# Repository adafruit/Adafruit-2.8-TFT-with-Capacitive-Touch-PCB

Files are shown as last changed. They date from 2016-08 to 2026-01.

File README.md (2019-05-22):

## Adafruit 2.8 TFT with Capacitive Touch PCB
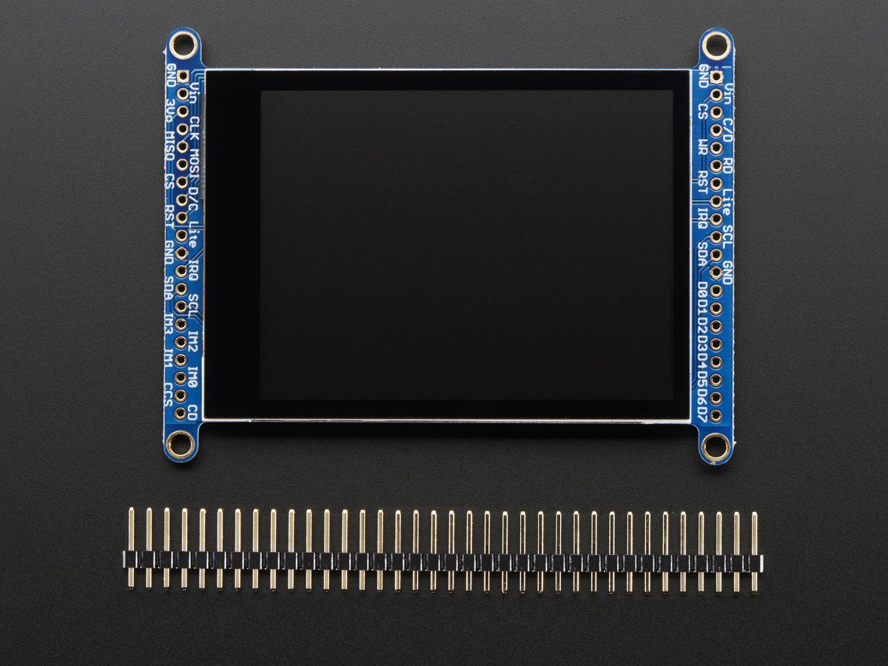
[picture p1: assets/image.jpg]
<a href="http://www.adafruit.com/products/2090"><br/>
Click here to purchase one from the Adafruit shop</a>

Add some jazz & pizazz to your project with a color capactive touchscreen LCD. This TFT display is big (2.8" diagonal) bright (4 white-LED backlight) and colorful! 240x320 pixels with individual RGB pixel control, this has way more resolution than a black and white 128x64 display. As a bonus, this display has a capacitive single-touch touchscreen attached to it already, so you can detect finger presses anywhere on the screen. (We also have a resistive touchscreen version of this display breakout)

This display has a controller built into it with RAM buffering, so that almost no work is done by the microcontroller. The display can be used in two modes: 8-bit and SPI. For 8-bit mode, you'll need 8 digital data lines and 4 or 5 digital control lines to read and write to the display (12 lines total). SPI mode requires only 5 pins total (SPI data in, data out, clock, select, and d/c) but is slower than 8-bit mode. In addition, 2 I2C pins are required for the touch screen controller.

We wrapped up this display into an easy-to-use breakout board, with SPI connections on one end and 8-bit on the other. Both are 3-5V compliant with high-speed level shifters so you can use with any microcontroller. If you're going with SPI mode, you can also take advantage of the onboard MicroSD card socket to display images. (The microSD card not included, but any will work).

PCB files for the Adafruit 2.8" TFT with Capacitive Touch PCB. The format is EagleCAD schematic and board layout
- https://www.adafruit.com/products/2090

### License

Adafruit invests time and resources providing this open source design, please support Adafruit and open-source hardware by purchasing products from [Adafruit](https://www.adafruit.com)!

All text above must be included in any redistribution

Designed by Limor Fried/Ladyada for Adafruit Industries.
Creative Commons Attribution/Share-Alike, all text above must be included in any redistribution. 
See license.txt for additional information.

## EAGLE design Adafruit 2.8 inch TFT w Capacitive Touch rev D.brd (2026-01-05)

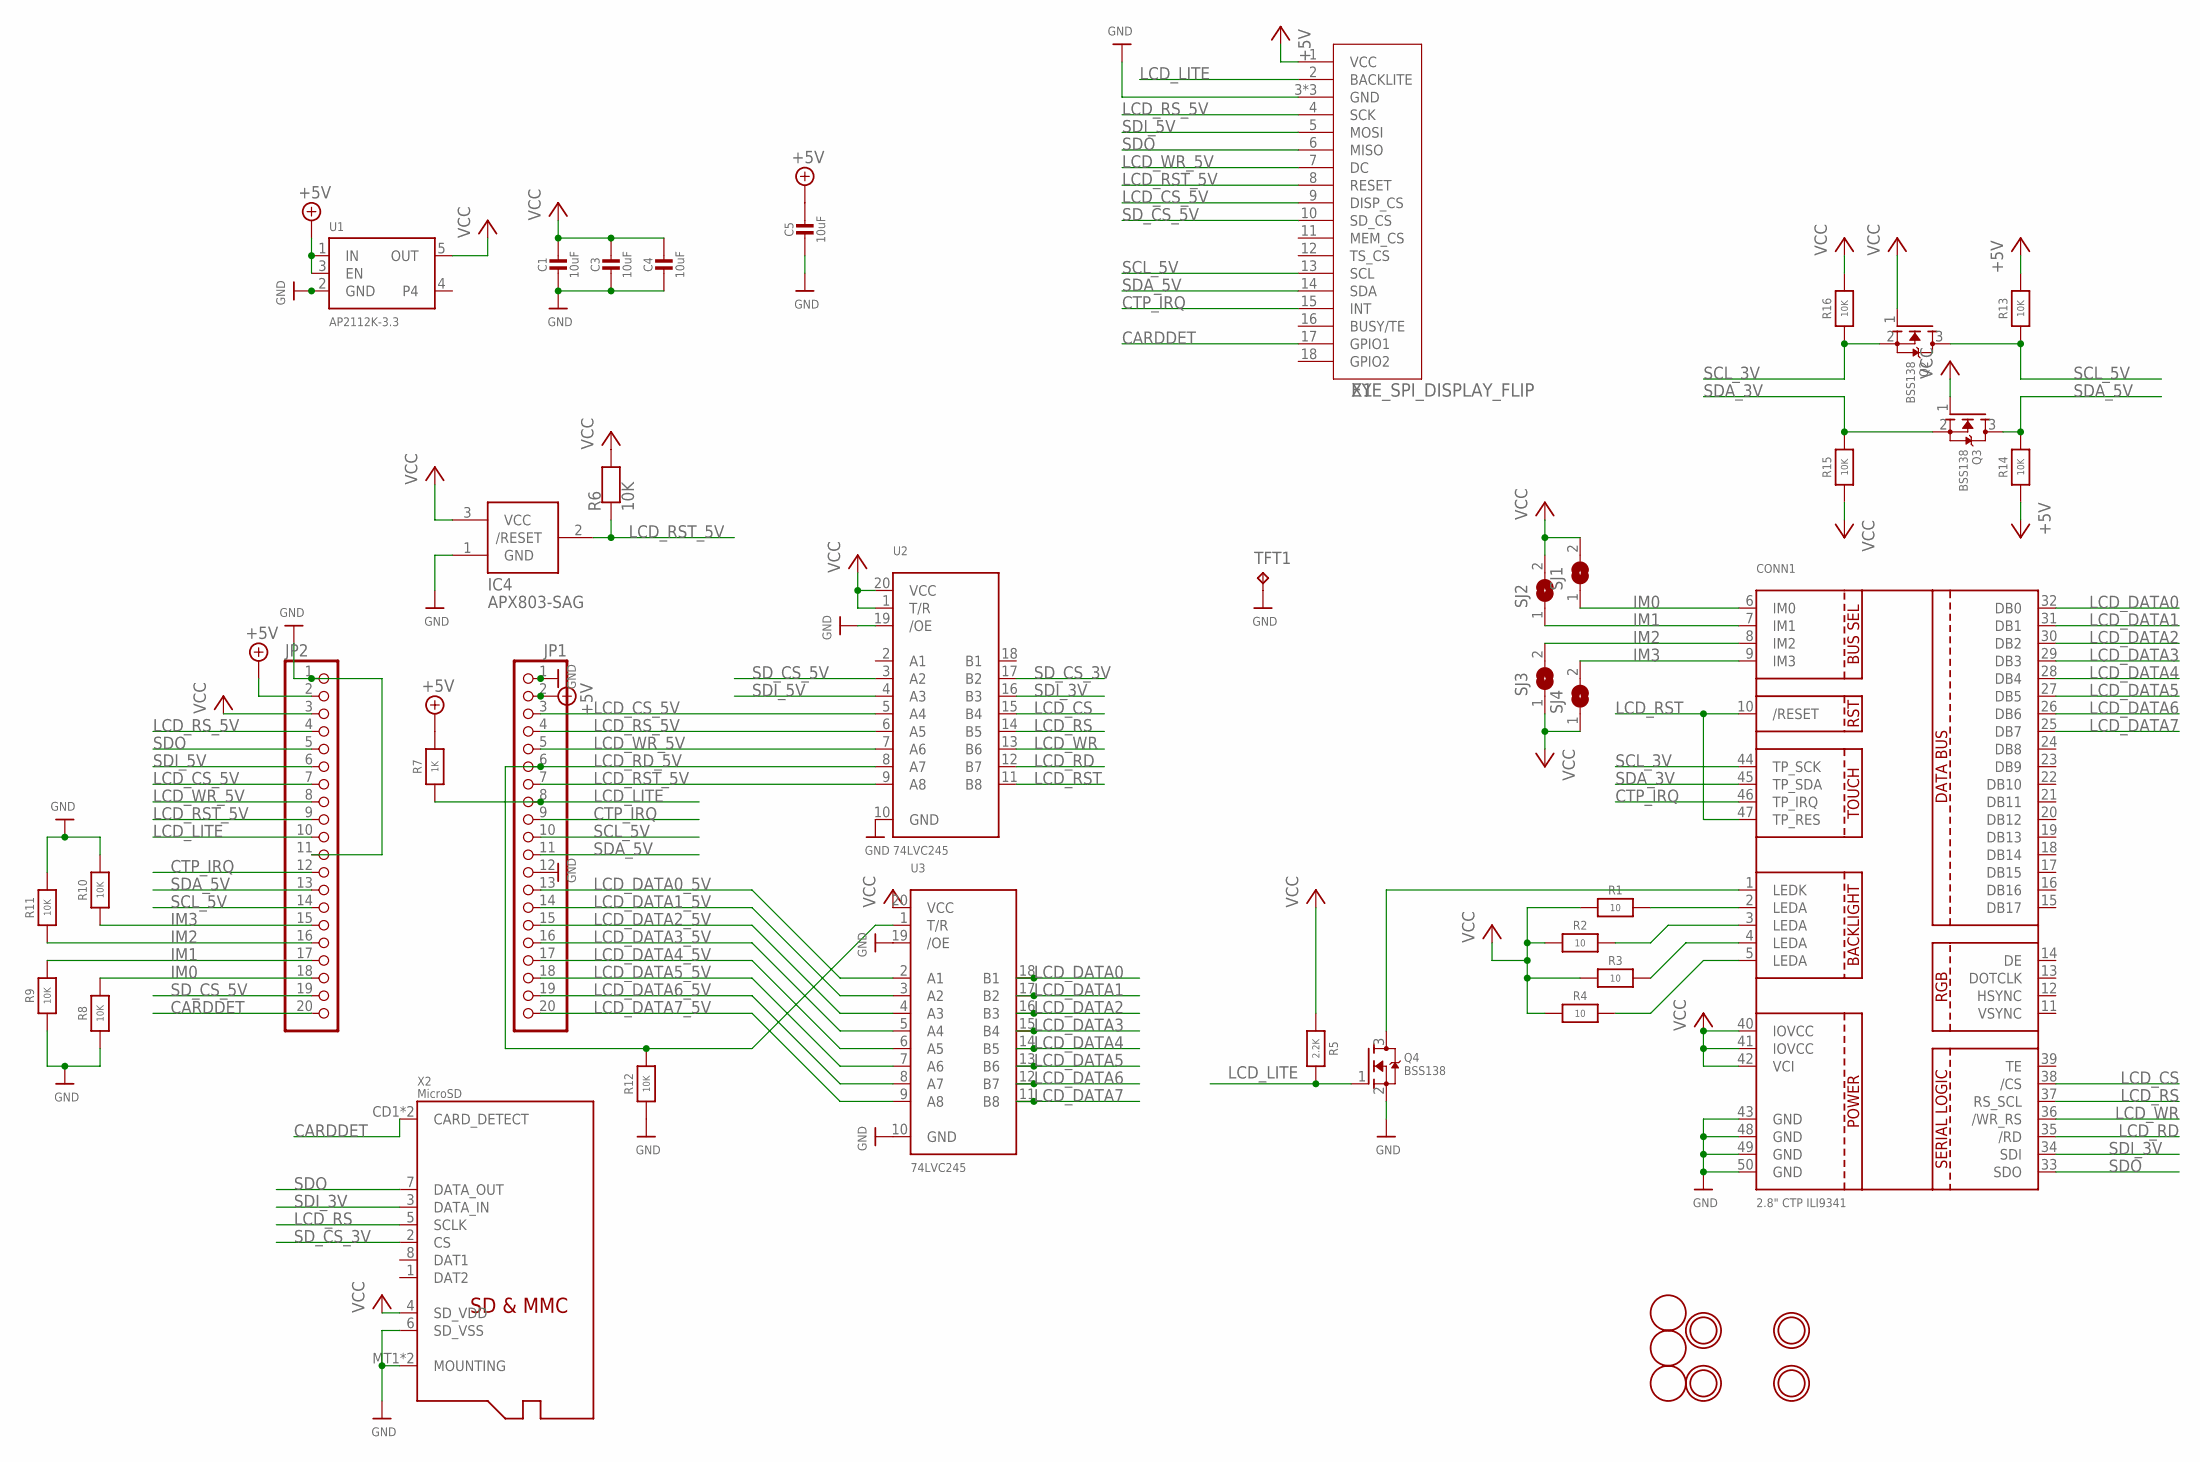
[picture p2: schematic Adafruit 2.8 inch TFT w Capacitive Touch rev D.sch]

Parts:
C1, C3, C4, C5: 10uF; 0805-NO
CONN1: 2.8" CTP ILI9341; TFT_2.83IN_240X320_50PIN
IC4: APX803-SAG; SOT23-WIDE
JP1, JP2: HEADER-1X20ROUND; 1X20_ROUND
Q2, Q3, Q4: BSS138; SOT23-WIDE
R1, R2, R3, R4: 10; 0603-NO
R5: 2.2K; 0603-NO
R6, R8, R9, R10, R11, R12, R13, R14, R15, R16: 10K; 0603-NO
R7: 1K; 0603-NO
SJ1, SJ2, SJ3, SJ4: SOLDERJUMPER; SOLDERJUMPER_ARROW_NOPASTE
TFT1: 2.8in CTP TFT; TP06R
U1: AP2112K-3.3; SOT23-5; JLC_ROTATION 0
U2, U3: 74LVC245; TSSOP20
U$7, U$15, U$16, U$17: MOUNTINGHOLE3.0THIN; MOUNTINGHOLE_3.0_PLATEDTHIN
U$9, U$11, U$23: FIDUCIAL; FIDUCIAL_1MM
X1: EYE_SPI_DISPLAY_FLIP; EYE_SPI_DISPLAY_BOTCONTACT
X2: MicroSD; MICROSD

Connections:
+5V: C5.1, JP1.2, JP2.2, R7.2, R13.2, R14.1, U1.1 (IN), U1.3 (EN), X1.1 (VCC)
CARDDET: JP2.20, X1.17 (GPIO1), X2.CD1 (CARD_DETECT), X2.CD2 (CARD_DETECT)
CTP_IRQ: CONN1.46 (TP_IRQ), JP1.9, JP2.12, X1.15 (INT)
GND: C1.2, C3.2, C4.2, C5.2, CONN1.43 (GND), CONN1.48 (GND), CONN1.49 (GND), CONN1.50 (GND), IC4.1 (GND), JP1.1, JP1.12, JP2.1, JP2.11, Q4.2 (S), R8.1, R9.1, R10.2, R11.2, R12.1, TFT1.TP, U1.2 (GND), U2.10 (GND), U2.19 (/OE), U3.10 (GND), U3.19 (/OE), X1.3 (GND), X1.SUPPORT1 (GND), X1.SUPPORT2 (GND), X2.6 (SD_VSS), X2.MT1 (MOUNTING), X2.MT2 (MOUNTING)
IM0: CONN1.6 (IM0), JP2.18, R8.2, SJ1.1
IM1: CONN1.7 (IM1), JP2.17, R9.2, SJ2.1
IM2: CONN1.8 (IM2), JP2.16, R11.1, SJ3.2
IM3: CONN1.9 (IM3), JP2.15, R10.1, SJ4.2
LCD_CS: CONN1.38 (/CS), U2.15 (B4)
LCD_CS_5V: JP1.3, JP2.7, U2.5 (A4), X1.9 (DISP_CS)
LCD_DATA0: CONN1.32 (DB0), U3.18 (B1)
LCD_DATA0_5V: JP1.13, U3.2 (A1)
LCD_DATA1: CONN1.31 (DB1), U3.17 (B2)
LCD_DATA1_5V: JP1.14, U3.3 (A2)
LCD_DATA2: CONN1.30 (DB2), U3.16 (B3)
LCD_DATA2_5V: JP1.15, U3.4 (A3)
LCD_DATA3: CONN1.29 (DB3), U3.15 (B4)
LCD_DATA3_5V: JP1.16, U3.5 (A4)
LCD_DATA4: CONN1.28 (DB4), U3.14 (B5)
LCD_DATA4_5V: JP1.17, U3.6 (A5)
LCD_DATA5: CONN1.27 (DB5), U3.13 (B6)
LCD_DATA5_5V: JP1.18, U3.7 (A6)
LCD_DATA6: CONN1.26 (DB6), U3.12 (B7)
LCD_DATA6_5V: JP1.19, U3.8 (A7)
LCD_DATA7: CONN1.25 (DB7), U3.11 (B8)
LCD_DATA7_5V: JP1.20, U3.9 (A8)
LCD_LITE: JP1.8, JP2.10, Q4.1 (G), R5.2, R7.1, X1.2 (BACKLITE)
LCD_RD: CONN1.35 (/RD), U2.12 (B7)
LCD_RD_5V: JP1.6, R12.2, U2.8 (A7), U3.1 (T/R)
LCD_RS: CONN1.37 (RS_SCL), U2.14 (B5), X2.5 (SCLK)
LCD_RST: CONN1.10 (/RESET), CONN1.47 (TP_RES), U2.11 (B8)
LCD_RST_5V: IC4.2 (/RESET), JP1.7, JP2.9, R6.1, U2.9 (A8), X1.8 (RESET)
LCD_RS_5V: JP1.4, JP2.4, U2.6 (A5), X1.4 (SCK)
LCD_WR: CONN1.36 (/WR_RS), U2.13 (B6)
LCD_WR_5V: JP1.5, JP2.8, U2.7 (A6), X1.7 (DC)
unnamed: CONN1.5 (LEDA), R4.2
unnamed: CONN1.2 (LEDA), R1.2
unnamed: CONN1.3 (LEDA), R2.2
unnamed: CONN1.4 (LEDA), R3.2
unnamed: CONN1.1 (LEDK), Q4.3 (D)
SCL_3V: CONN1.44 (TP_SCK), Q2.2 (S), R16.1
SCL_5V: JP1.10, JP2.14, Q2.3 (D), R13.1, X1.13 (SCL)
SDA_3V: CONN1.45 (TP_SDA), Q3.2 (S), R15.2
SDA_5V: JP1.11, JP2.13, Q3.3 (D), R14.2, X1.14 (SDA)
SDI_3V: CONN1.34 (SDI), U2.16 (B3), X2.3 (DATA_IN)
SDI_5V: JP2.6, U2.4 (A3), X1.5 (MOSI)
SDO: CONN1.33 (SDO), JP2.5, X1.6 (MISO), X2.7 (DATA_OUT)
SD_CS_3V: U2.17 (B2), X2.2 (CS)
SD_CS_5V: JP2.19, U2.3 (A2), X1.10 (SD_CS)
VCC: C1.1, C3.1, C4.1, CONN1.40 (IOVCC), CONN1.41 (IOVCC), CONN1.42 (VCI), IC4.3 (VCC), JP2.3, Q2.1 (G), Q3.1 (G), R1.1, R2.1, R3.1, R4.1, R5.1, R6.2, R15.1, R16.2, SJ1.2, SJ2.2, SJ3.1, SJ4.1, U1.5 (OUT), U2.1 (T/R), U2.20 (VCC), U3.20 (VCC), X2.4 (SD_VDD)

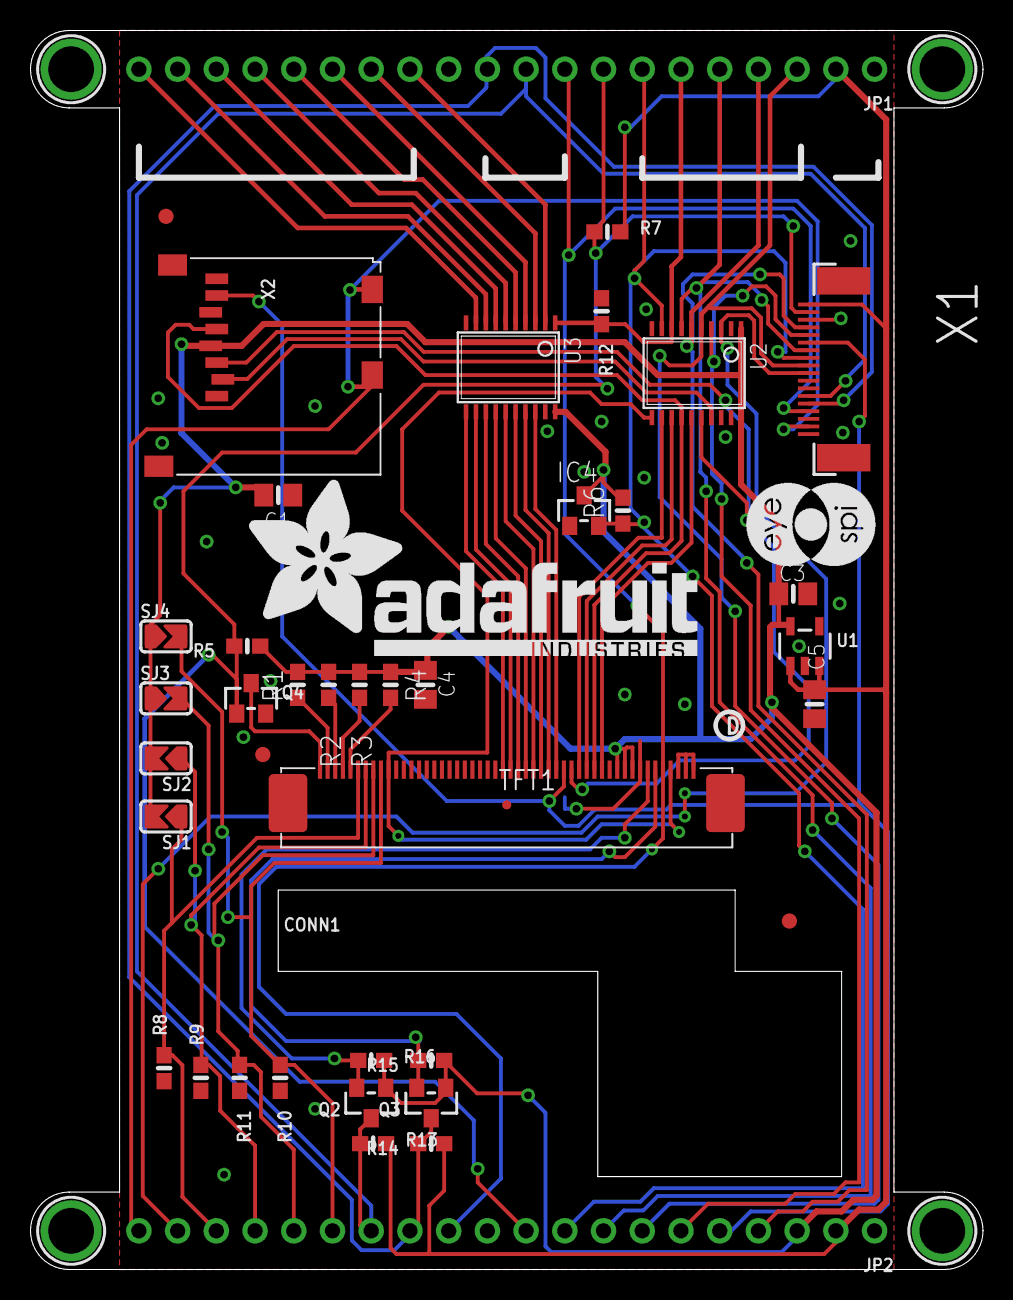
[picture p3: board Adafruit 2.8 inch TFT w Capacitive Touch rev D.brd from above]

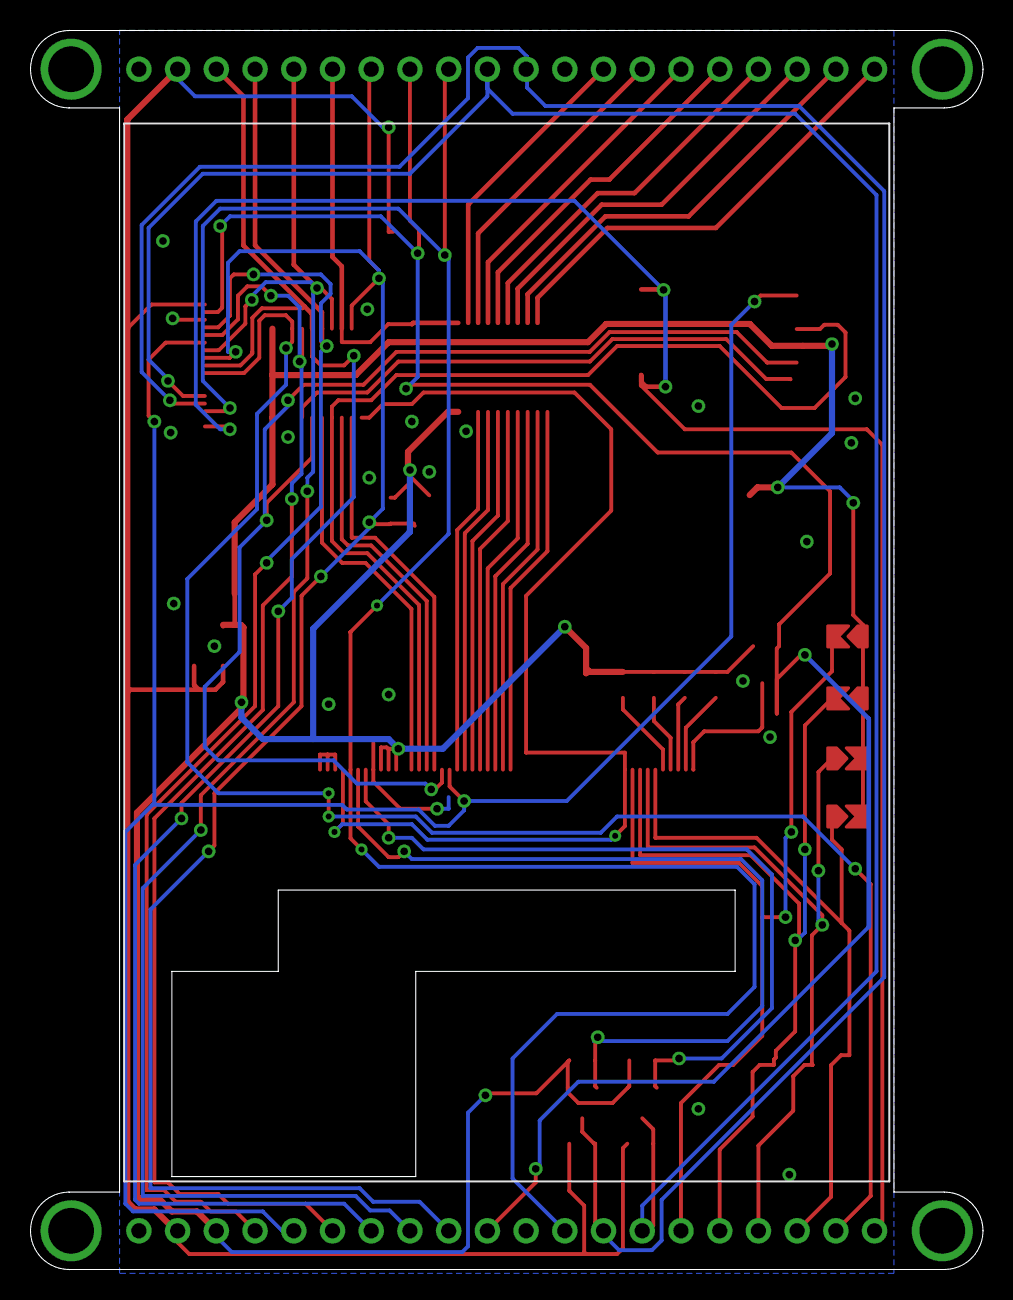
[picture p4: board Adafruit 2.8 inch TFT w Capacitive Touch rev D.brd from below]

Board: 2 copper layers, 62.5 x 81.3 mm, 144 parts (41 on the bottom side), 50 nets.

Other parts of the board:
PLABEL0: PLABEL0
PLABEL1: PLABEL1
PLABEL2: PLABEL2
PLABEL3: PLABEL3
PLABEL4: PLABEL4
PLABEL5: PLABEL5
PLABEL6: PLABEL6
PLABEL7: PLABEL7
PLABEL8: PLABEL8
PLABEL9: PLABEL9
PLABEL10: PLABEL10
PLABEL11: PLABEL11
PLABEL12: PLABEL12
PLABEL13: PLABEL13
PLABEL14: PLABEL14
PLABEL15: PLABEL15
PLABEL16: PLABEL16
PLABEL17: PLABEL17
PLABEL18: PLABEL18
PLABEL19: PLABEL19
PLABEL20: PLABEL20
PLABEL21: PLABEL21
PLABEL22: PLABEL22
PLABEL23: PLABEL23
PLABEL24: PLABEL24
PLABEL25: PLABEL25
PLABEL26: PLABEL26
PLABEL27: PLABEL27
PLABEL28: PLABEL28
PLABEL29: PLABEL29
PLABEL30: PLABEL30
PLABEL31: PLABEL31
PLABEL32: PLABEL32
PLABEL33: PLABEL33
PLABEL34: PLABEL34
PLABEL35: PLABEL35
PLABEL36: PLABEL36
PLABEL37: PLABEL37
PLABEL38: PLABEL38
PLABEL39: PLABEL39
PLABEL40: PLABEL40
PLABEL41: PLABEL41
PLABEL42: PLABEL42
PLABEL43: PLABEL43
PLABEL44: PLABEL44
PLABEL45: PLABEL45
PLABEL46: PLABEL46
PLABEL47: PLABEL47
PLABEL48: PLABEL48
PLABEL49: PLABEL49
PLABEL50: PLABEL50
PLABEL51: PLABEL51
PLABEL52: PLABEL52
PLABEL53: PLABEL53
PLABEL54: PLABEL54
PLABEL55: PLABEL55
PLABEL56: PLABEL56
PLABEL57: PLABEL57
PLABEL58: PLABEL58
PLABEL59: PLABEL59
PLABEL60: PLABEL60
PLABEL61: PLABEL61
PLABEL62: PLABEL62
PLABEL63: PLABEL63
PLABEL64: PLABEL64
PLABEL65: PLABEL65
PLABEL66: PLABEL66
PLABEL67: PLABEL67
PLABEL68: PLABEL68
PLABEL69: PLABEL69
PLABEL70: PLABEL70
PLABEL71: PLABEL71
PLABEL72: PLABEL72
PLABEL73: PLABEL73
PLABEL74: PLABEL74
PLABEL75: PLABEL75
PLABEL76: PLABEL76
PLABEL77: PLABEL77
PLABEL78: PLABEL78
PLABEL79: PLABEL79
PLABEL80: PLABEL80
PLABEL81: PLABEL81
PLABEL82: PLABEL82
PLABEL83: PLABEL83
PLABEL84: PLABEL84
PLABEL85: PLABEL85
PLABEL86: PLABEL86
PLABEL87: PLABEL87
PLABEL88: PLABEL88
PLABEL89: PLABEL89
PLABEL90: PLABEL90
PLABEL91: PLABEL91
PLABEL92: PLABEL92
PLABEL93: PLABEL93
PLABEL94: PLABEL94
PLABEL95: PLABEL95
PLABEL96: PLABEL96
U$19: ADAFRUIT_TEXT_30MM
U$28: PCBFEAT-REV-040
U$29: EYESPI_MINI_LOGO

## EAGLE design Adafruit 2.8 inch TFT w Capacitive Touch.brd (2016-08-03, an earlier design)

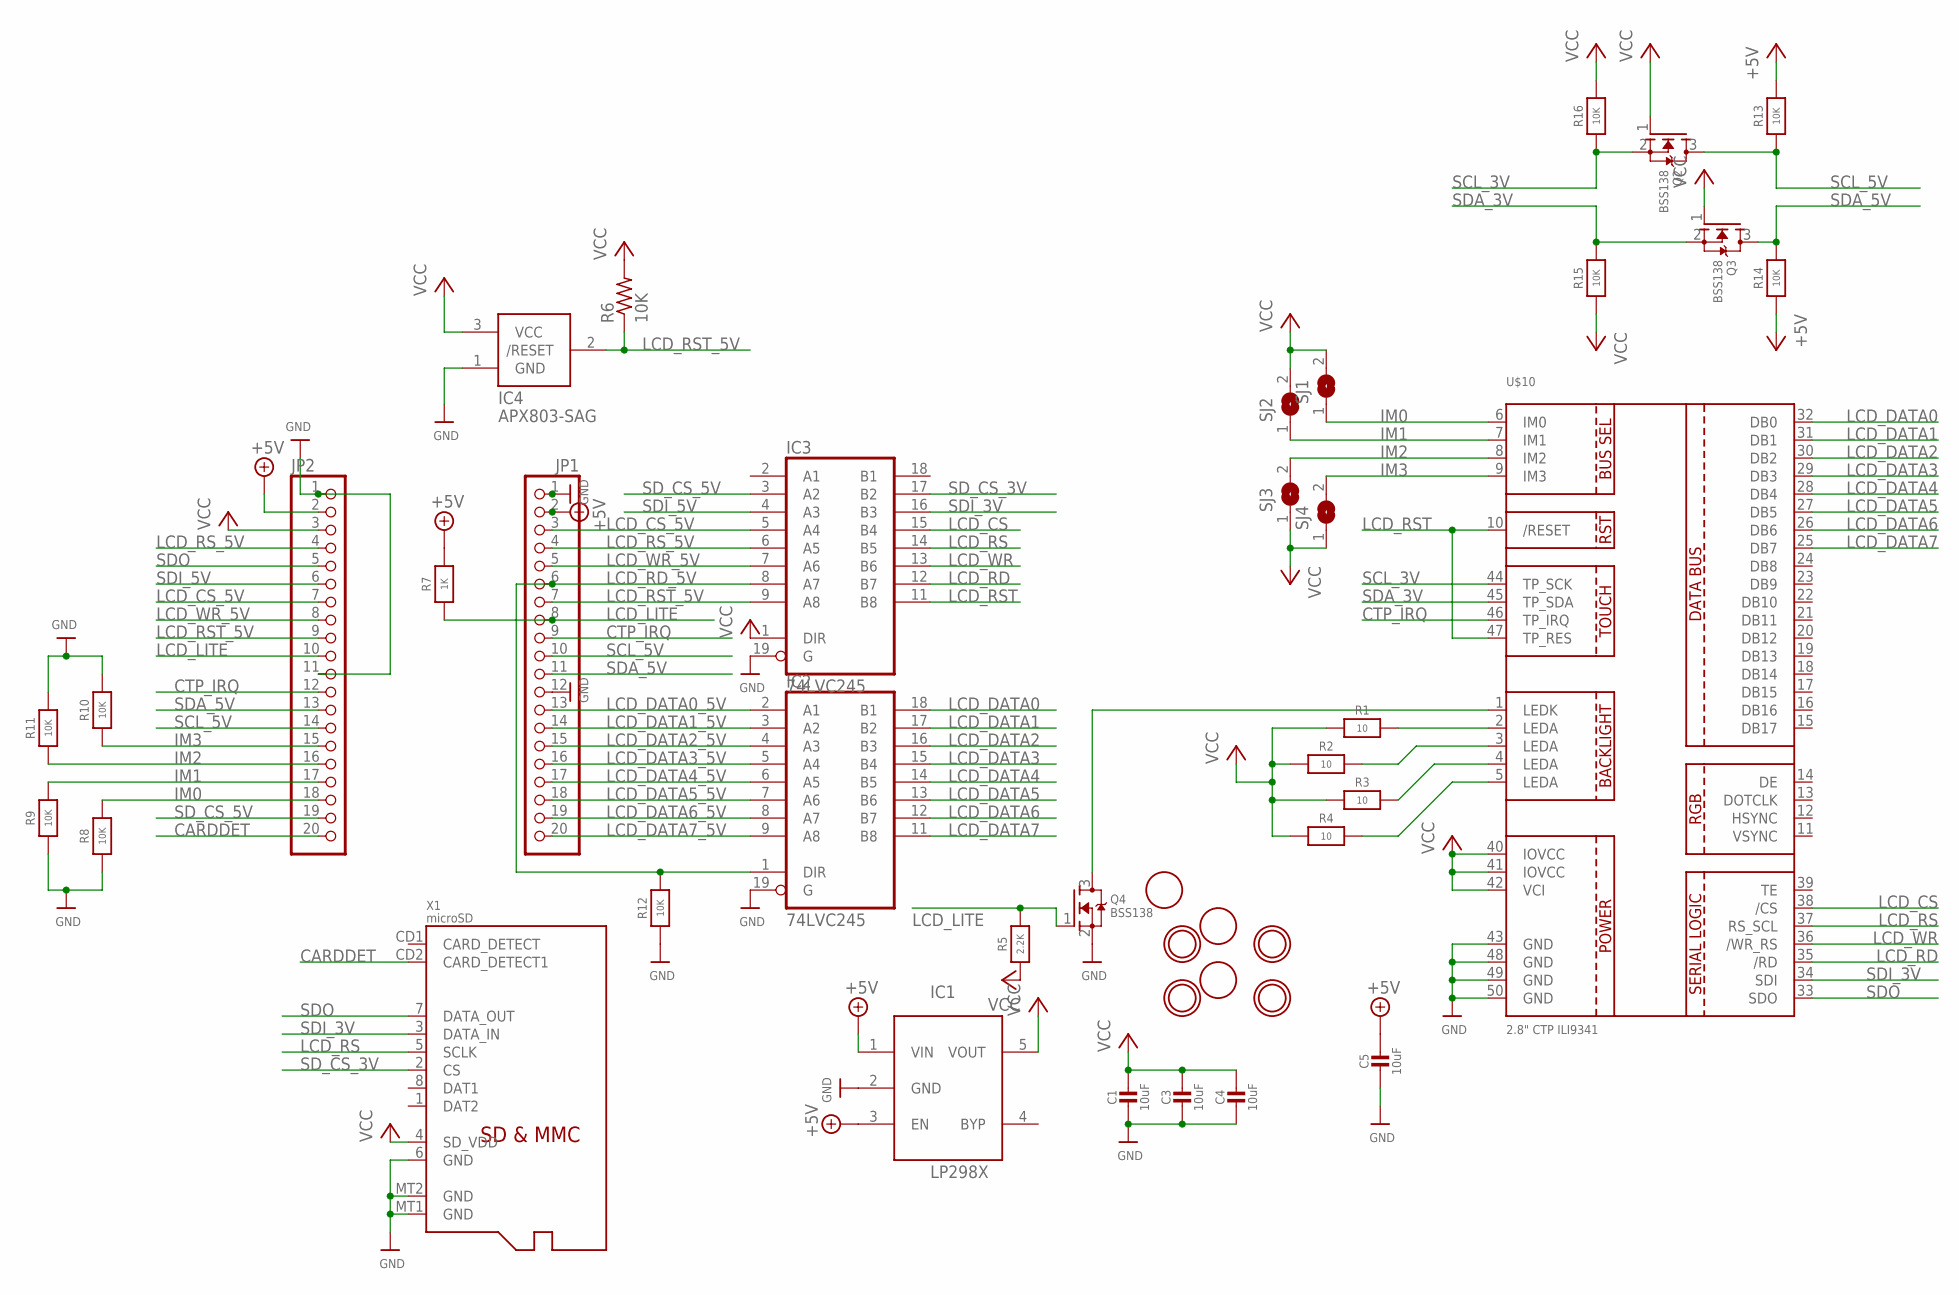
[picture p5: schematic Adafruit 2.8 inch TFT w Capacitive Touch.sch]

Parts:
C1, C3, C4, C5: 10uF; 0805-NO
IC1: MIC5225-3.3; SOT23-5L
IC2, IC3: 74LVC245; SO20W
IC4: APX803-SAG; SOT23
JP1, JP2: HEADER-1X20ROUND; 1X20_ROUND
Q2, Q3, Q4: BSS138; SOT23-WIDE
R1, R2, R3, R4: 10; 0805-NO
R5: 2.2K; 0805-NO
R6: 10K; R0805
R7: 1K; 0805-NO
R8, R9, R10, R11, R12, R13, R14, R15, R16: 10K; 0805-NO
SJ1, SJ2, SJ3, SJ4: SOLDERJUMPER; SOLDERJUMPER_ARROW_NOPASTE
U$7, U$15, U$16, U$17: MOUNTINGHOLE3.0THIN; MOUNTINGHOLE_3.0_PLATEDTHIN
U$9, U$11, U$23: FIDUCIAL; FIDUCIAL_1MM
U$10: 2.8" CTP ILI9341; TFT_2.83IN_240X320_50PIN
X1: microSD; MICROSD

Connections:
+5V: C5.1, IC1.1 (VIN), IC1.3 (EN), JP1.2, JP2.2, R7.2, R13.2, R14.1
CARDDET: JP2.20, X1.CD2 (CARD_DETECT1)
CTP_IRQ: JP1.9, JP2.12, U$10.46 (TP_IRQ)
GND: C1.2, C3.2, C4.2, C5.2, IC1.2 (GND), IC2.10 (GND), IC2.19 (G), IC3.10 (GND), IC3.19 (G), IC4.1 (GND), JP1.1, JP1.12, JP2.1, JP2.11, Q4.2 (S), R8.1, R9.1, R10.2, R11.2, R12.1, U$10.43 (GND), U$10.48 (GND), U$10.49 (GND), U$10.50 (GND), X1.6 (GND), X1.MT1 (GND), X1.MT2 (GND)
IM0: JP2.18, R8.2, SJ1.1, U$10.6 (IM0)
IM1: JP2.17, R9.2, SJ2.1, U$10.7 (IM1)
IM2: JP2.16, R11.1, SJ3.2, U$10.8 (IM2)
IM3: JP2.15, R10.1, SJ4.2, U$10.9 (IM3)
LCD_CS: IC3.15 (B4), U$10.38 (/CS)
LCD_CS_5V: IC3.5 (A4), JP1.3, JP2.7
LCD_DATA0: IC2.18 (B1), U$10.32 (DB0)
LCD_DATA0_5V: IC2.2 (A1), JP1.13
LCD_DATA1: IC2.17 (B2), U$10.31 (DB1)
LCD_DATA1_5V: IC2.3 (A2), JP1.14
LCD_DATA2: IC2.16 (B3), U$10.30 (DB2)
LCD_DATA2_5V: IC2.4 (A3), JP1.15
LCD_DATA3: IC2.15 (B4), U$10.29 (DB3)
LCD_DATA3_5V: IC2.5 (A4), JP1.16
LCD_DATA4: IC2.14 (B5), U$10.28 (DB4)
LCD_DATA4_5V: IC2.6 (A5), JP1.17
LCD_DATA5: IC2.13 (B6), U$10.27 (DB5)
LCD_DATA5_5V: IC2.7 (A6), JP1.18
LCD_DATA6: IC2.12 (B7), U$10.26 (DB6)
LCD_DATA6_5V: IC2.8 (A7), JP1.19
LCD_DATA7: IC2.11 (B8), U$10.25 (DB7)
LCD_DATA7_5V: IC2.9 (A8), JP1.20
LCD_LITE: JP1.8, JP2.10, Q4.1 (G), R5.2, R7.1
LCD_RD: IC3.12 (B7), U$10.35 (/RD)
LCD_RD_5V: IC2.1 (DIR), IC3.8 (A7), JP1.6, R12.2
LCD_RS: IC3.14 (B5), U$10.37 (RS_SCL), X1.5 (SCLK)
LCD_RST: IC3.11 (B8), U$10.10 (/RESET), U$10.47 (TP_RES)
LCD_RST_5V: IC3.9 (A8), IC4.2 (/RESET), JP1.7, JP2.9, R6.1
LCD_RS_5V: IC3.6 (A5), JP1.4, JP2.4
LCD_WR: IC3.13 (B6), U$10.36 (/WR_RS)
LCD_WR_5V: IC3.7 (A6), JP1.5, JP2.8
unnamed: R4.2, U$10.5 (LEDA)
unnamed: R1.2, U$10.2 (LEDA)
unnamed: R2.2, U$10.3 (LEDA)
unnamed: R3.2, U$10.4 (LEDA)
unnamed: Q4.3 (D), U$10.1 (LEDK)
SCL_3V: Q2.2 (S), R16.1, U$10.44 (TP_SCK)
SCL_5V: JP1.10, JP2.14, Q2.3 (D), R13.1
SDA_3V: Q3.2 (S), R15.2, U$10.45 (TP_SDA)
SDA_5V: JP1.11, JP2.13, Q3.3 (D), R14.2
SDI_3V: IC3.16 (B3), U$10.34 (SDI), X1.3 (DATA_IN)
SDI_5V: IC3.4 (A3), JP2.6
SDO: JP2.5, U$10.33 (SDO), X1.7 (DATA_OUT)
SD_CS_3V: IC3.17 (B2), X1.2 (CS)
SD_CS_5V: IC3.3 (A2), JP2.19
VCC: C1.1, C3.1, C4.1, IC1.5 (VOUT), IC2.20 (VCC), IC3.1 (DIR), IC3.20 (VCC), IC4.3 (VCC), JP2.3, Q2.1 (G), Q3.1 (G), R1.1, R2.1, R3.1, R4.1, R5.1, R6.2, R15.1, R16.2, SJ1.2, SJ2.2, SJ3.1, SJ4.1, U$10.40 (IOVCC), U$10.41 (IOVCC), U$10.42 (VCI), X1.4 (SD_VDD)

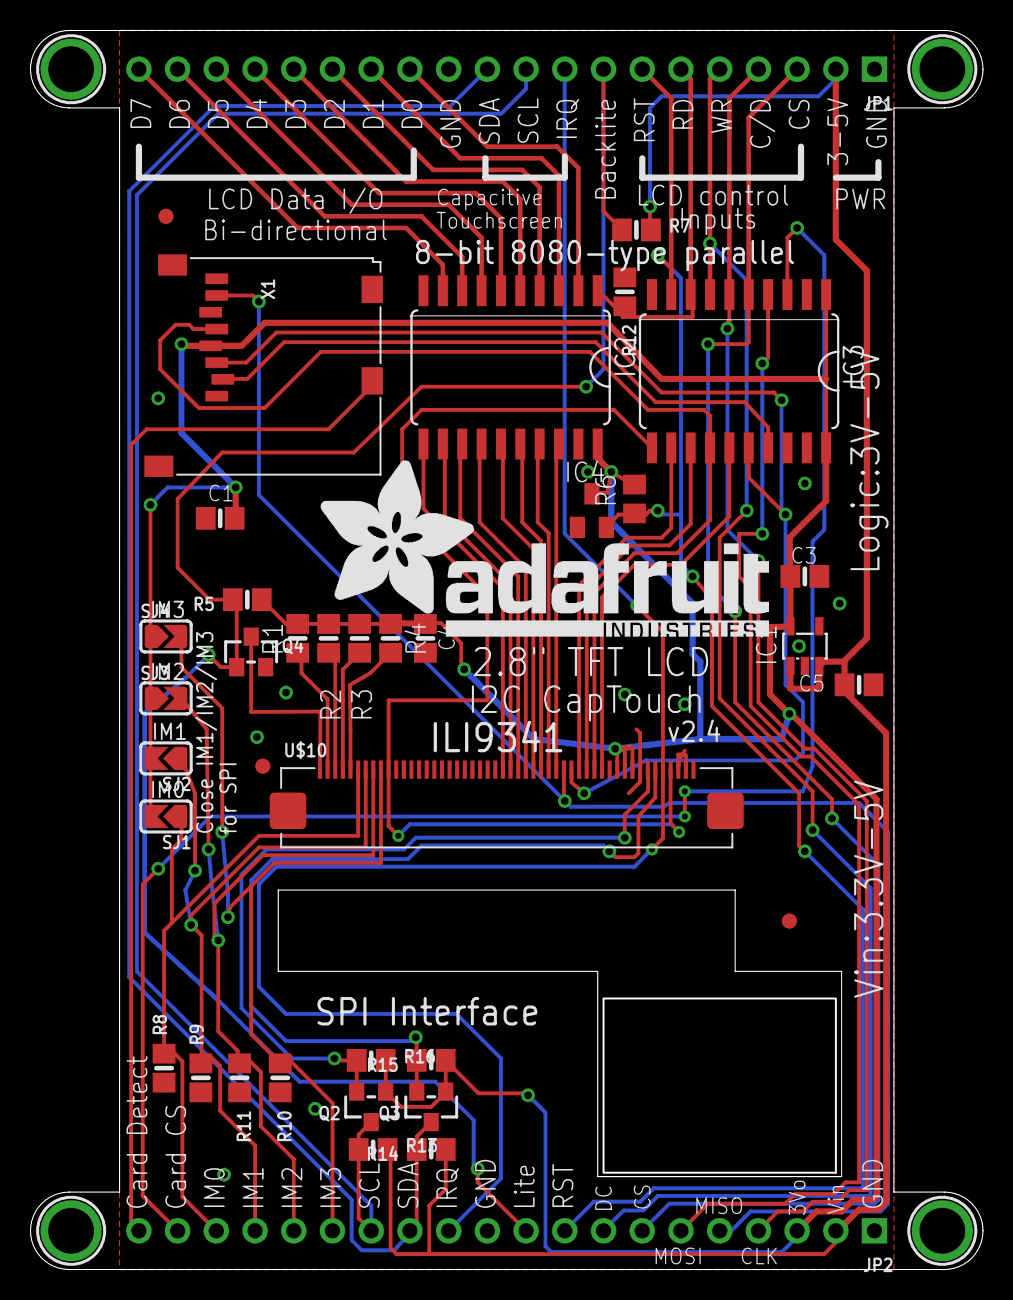
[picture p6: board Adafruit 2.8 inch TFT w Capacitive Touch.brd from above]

Board: 2 copper layers, 62.5 x 81.3 mm, 43 parts (1 on the bottom side), 50 nets.

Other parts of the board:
U$19: ADAFRUIT_TEXT_30MM

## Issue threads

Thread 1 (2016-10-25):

Missing ground pours?

gragib, 2016-10-25:
Seems to me as though the ground pours are missing, but my Eagle may be misconfigured. I'm new to Eagle. I have more experience with Altium Designer and KiCad.

gragib, 2016-10-25:
Never mind. I clicked on Tools > Ratsnest and I can see the ground pours.

This issue can be deleted.

Closed 2016-10-25.
